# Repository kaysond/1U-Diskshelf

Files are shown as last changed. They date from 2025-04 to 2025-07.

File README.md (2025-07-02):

# 1U-DiskShelf
A 3D-Printable 1U Disk Shelf (4 bays) With Custom SATA Backplane

Board files can be found in the Backplane PCB directory.

Models can be found on [MakerWorld](https://makerworld.com/en/models/1570200-1u-disk-shelf-19-inch-4-bay-10-inch-2-bay) or see the Models directory for CAD files

# License
This project is released under the CC BY-NC-SA 4.0 license. See LICENSE.txt or https://creativecommons.org/licenses/by-nc-sa/4.0/

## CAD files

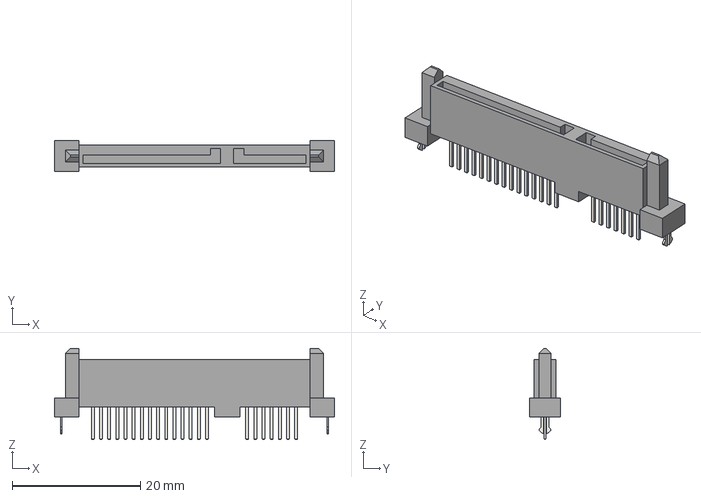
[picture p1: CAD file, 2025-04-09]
Backplane PCB/3D Models/SATA 7+15 Female.step
43.6 x 4.90 x 14.2 mm

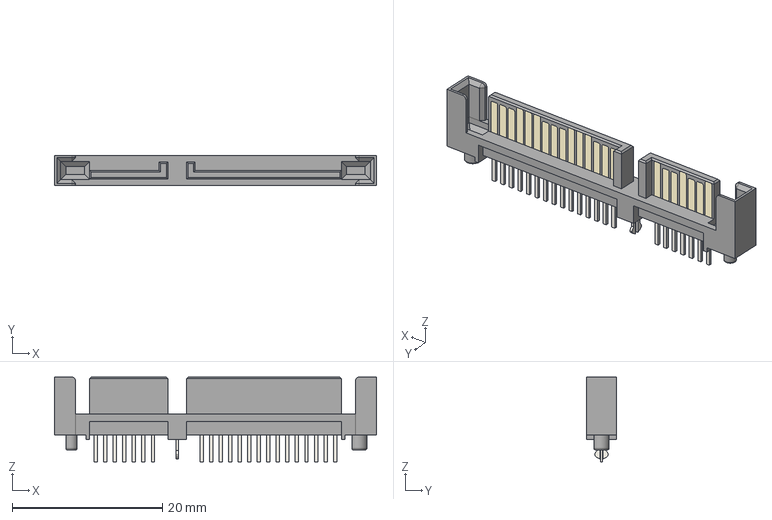
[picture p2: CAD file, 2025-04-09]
Backplane PCB/3D Models/SATA 7+15 Male.step
42.9 x 4.00 x 11.3 mm

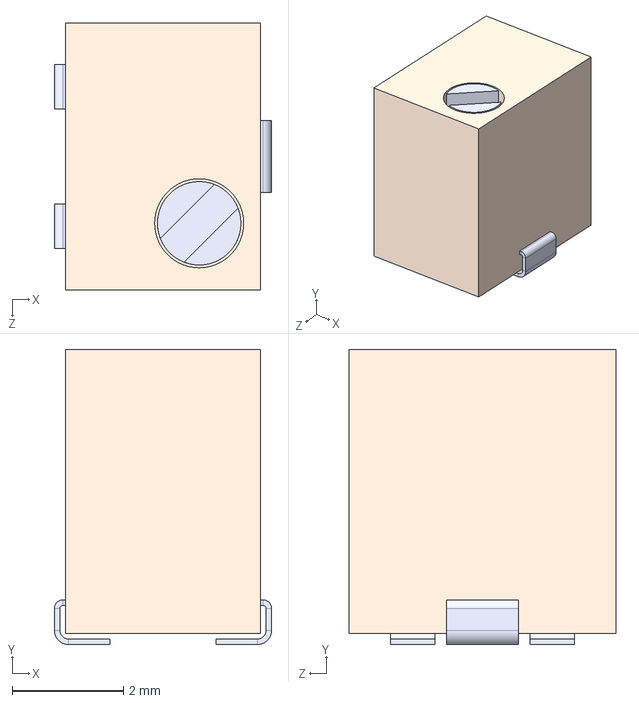
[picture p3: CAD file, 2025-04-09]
Backplane PCB/3D Models/3214W-1-102E.STEP
3.90 x 5.30 x 4.80 mm

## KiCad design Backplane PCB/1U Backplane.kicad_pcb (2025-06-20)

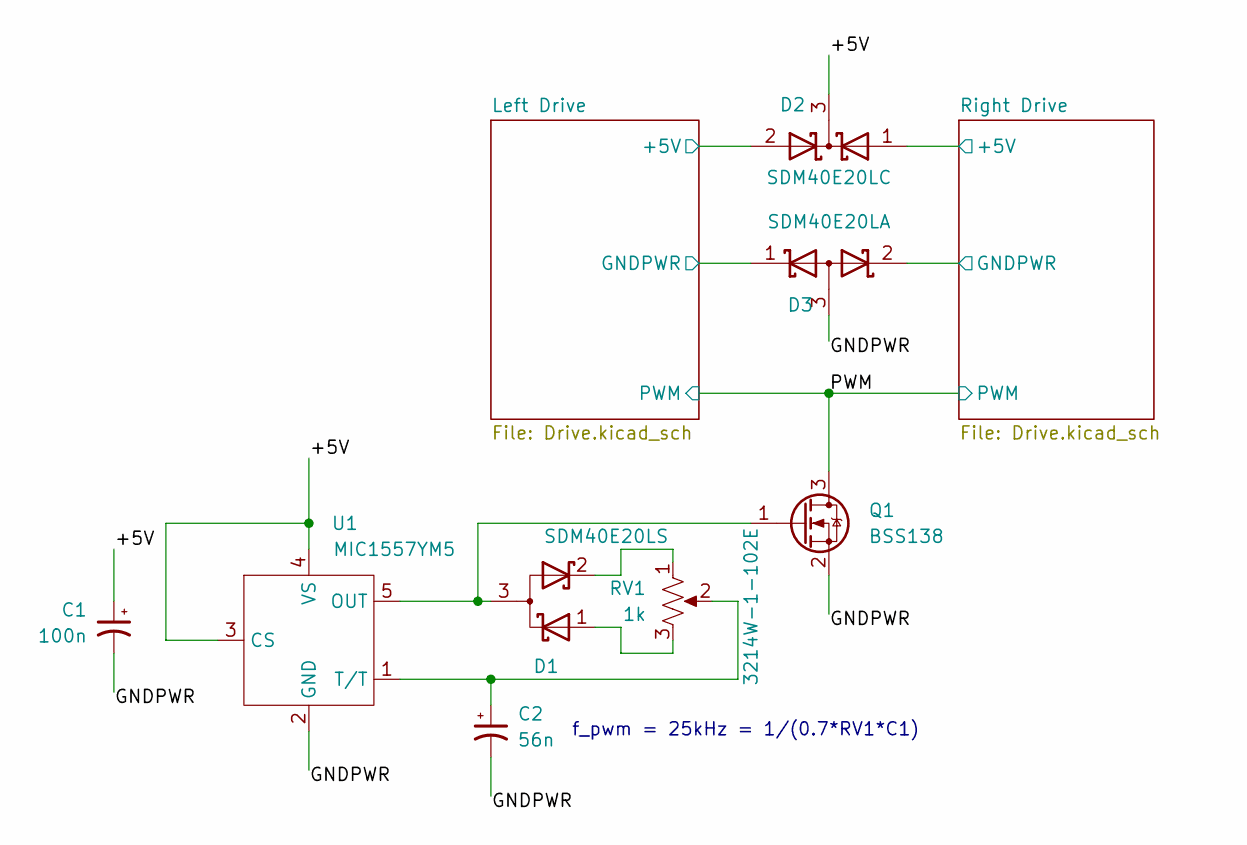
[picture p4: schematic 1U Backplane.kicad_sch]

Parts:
C1: 100n; C_0603_1608Metric_Pad1.08x0.95mm_HandSolder
C2: 56n; C_0603_1608Metric_Pad1.08x0.95mm_HandSolder
D1: SDM40E20LS; SOT-23
D2: SDM40E20LC; SOT-23
D3: SDM40E20LA; SOT-23
Q1: BSS138; SOT-23
RV1: 1k; Potentiometer_Bourns_3214W_Vertical; Part No 3214W-1-102E
U1: MIC1557YM5; SOT-23-5

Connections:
/+5V: C1.1, D2.3 (K), U1.3 (CS), U1.4 (VS)
/GNDPWR: C1.2, C2.2, D3.3 (A), Q1.2 (S), U1.2 (GND)
/Left Drive/+5V: D2.2 (A); also elsewhere on the board
/Left Drive/GNDPWR: D3.1 (K); also elsewhere on the board
/PWM: Q1.3 (D); also elsewhere on the board
/Right Drive/+5V: D2.1 (A); also elsewhere on the board
/Right Drive/GNDPWR: D3.2 (K); also elsewhere on the board
unnamed: D1.3 (A), Q1.1 (G), U1.5 (OUT)
unnamed: D1.1 (K), RV1.3
unnamed: D1.2 (K), RV1.1
unnamed: C2.1, RV1.2, U1.1 (T/T)

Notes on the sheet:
f_pwm = 25kHz = 1/(0.7*RV1*C1)

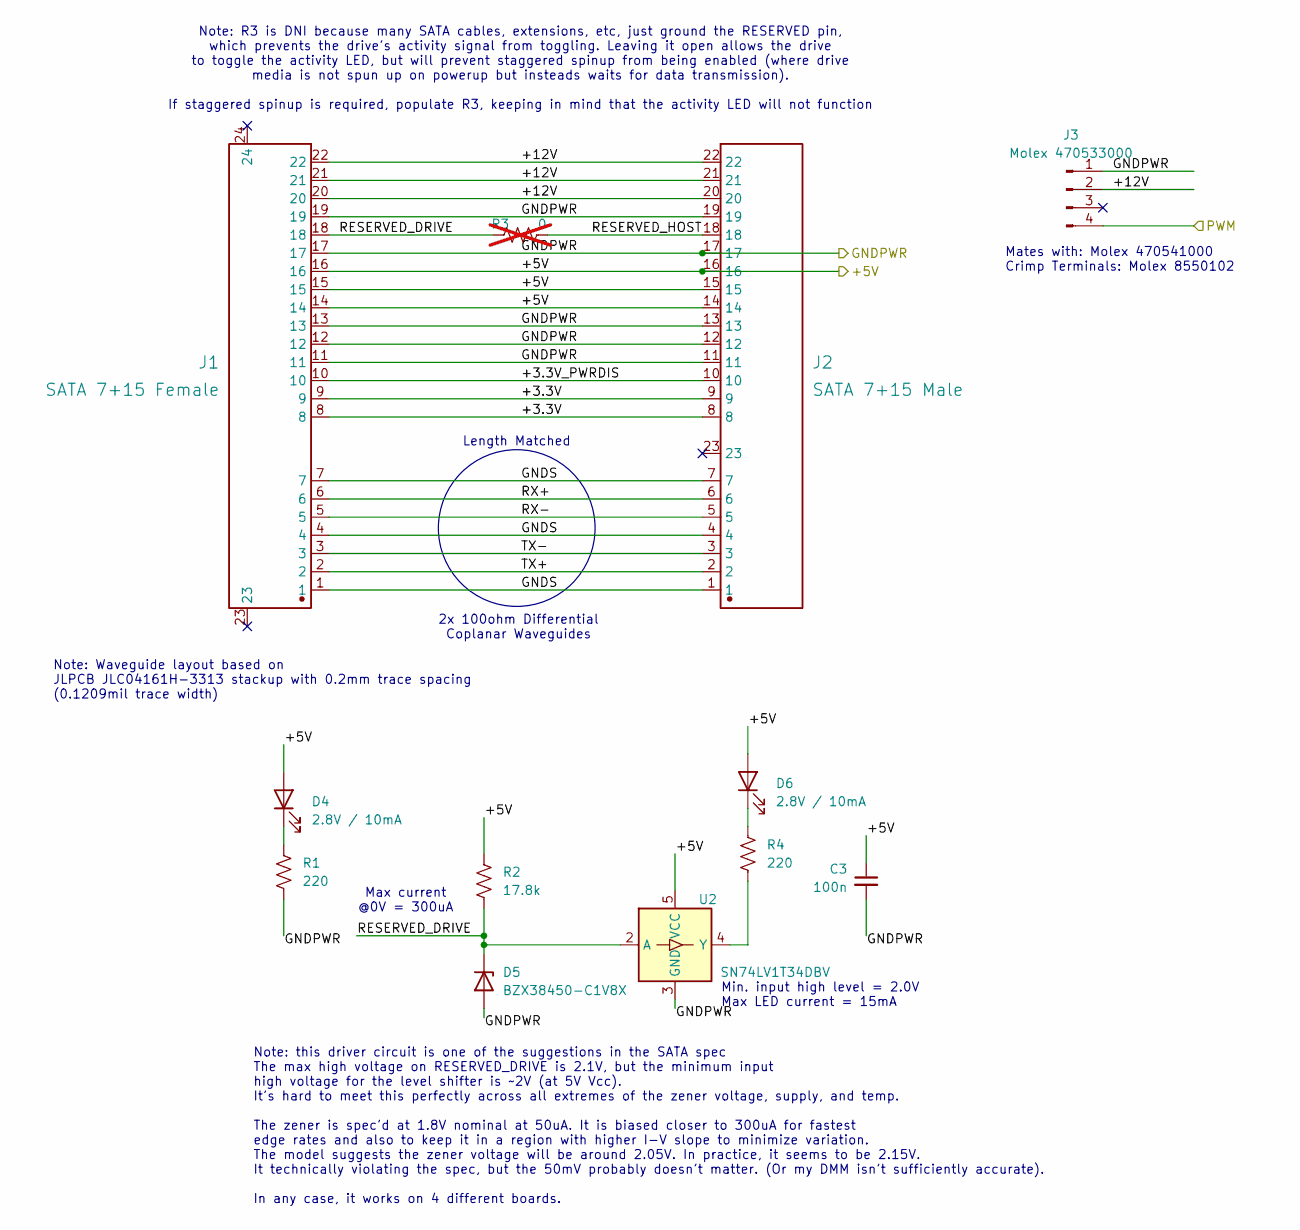
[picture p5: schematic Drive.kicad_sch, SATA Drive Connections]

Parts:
C3: 100n; C_0603_1608Metric_Pad1.08x0.95mm_HandSolder
D4, D6: 2.8V / 10mA; LED_0603_1608Metric_Pad1.05x0.95mm_HandSolder
D5: BZX38450-C1V8X; D_SOD-323_HandSoldering
J1: SATA 7+15 Female; CONN-TH_SATA7-15-TYPE-B; Manufacturer Part SATA 7+15 TYPE-B
J2: SATA 7+15 Male; CONN-TH_SATA7-15-TYPE-A; Manufacturer Part SATA 7+15 TYPE-A
J3: Molex 470533000; Molex_KK-254_AE-6410-04A_1x04_P2.54mm_Vertical
R1, R4: 220; R_0603_1608Metric_Pad0.98x0.95mm_HandSolder
R2: 17.8k; R_0603_1608Metric_Pad0.98x0.95mm_HandSolder
R3: 0; R_0402_1005Metric; not fitted
U2: SN74LV1T34DBV; SOT-23-5

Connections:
/Left Drive/+3.3V: J1.8, J1.9, J2.8, J2.9
/Left Drive/+3.3V_PWRDIS: J1.10, J2.10
/Left Drive/+5V: C3.1, D4.2 (A), D6.2 (A), J1.14, J1.15, J1.16, J2.14, J2.15, J2.16, R2.1, U2.5 (VCC); also elsewhere on the board
/Left Drive/+12V: J1.20, J1.21, J1.22, J2.20, J2.21, J2.22, J3.2
/Left Drive/GNDPWR: C3.2, D5.2 (A), J1.11, J1.12, J1.13, J1.17, J1.19, J2.11, J2.12, J2.13, J2.17, J2.19, J3.1, R1.2, U2.3 (GND); also elsewhere on the board
/Left Drive/GNDS: J1.1, J1.4, J1.7, J2.1, J2.4, J2.7
/Left Drive/RESERVED_DRIVE: D5.1 (K), J1.18, R2.2, R3.1, U2.2 (A)
/Left Drive/RESERVED_HOST: J2.18, R3.2
/Left Drive/RX+: J1.6, J2.6
/Left Drive/RX-: J1.5, J2.5
/Left Drive/TX+: J1.2, J2.2
/Left Drive/TX-: J1.3, J2.3
/PWM: J3.4; also elsewhere on the board
unnamed: D4.1 (K), R1.1
unnamed: D6.1 (K), R4.1
unnamed: R4.2, U2.4 (Y)

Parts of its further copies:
C4: 100n; C_0603_1608Metric_Pad1.08x0.95mm_HandSolder
D7, D9: 2.8V / 10mA; LED_0603_1608Metric_Pad1.05x0.95mm_HandSolder
D8: BZX38450-C1V8X; D_SOD-323_HandSoldering
J4: SATA 7+15 Female; CONN-TH_SATA7-15-TYPE-B; Manufacturer Part SATA 7+15 TYPE-B
J5: SATA 7+15 Male; CONN-TH_SATA7-15-TYPE-A; Manufacturer Part SATA 7+15 TYPE-A
J6: Molex 470533000; Molex_KK-254_AE-6410-04A_1x04_P2.54mm_Vertical
R5, R8: 220; R_0603_1608Metric_Pad0.98x0.95mm_HandSolder
R6: 17.8k; R_0603_1608Metric_Pad0.98x0.95mm_HandSolder
R7: 0; R_0402_1005Metric; not fitted
U3: SN74LV1T34DBV; SOT-23-5

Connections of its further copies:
/PWM: J6.4; also elsewhere on the board
/Right Drive/+3.3V: J4.8, J4.9, J5.8, J5.9
/Right Drive/+3.3V_PWRDIS: J4.10, J5.10
/Right Drive/+5V: C4.1, D7.2 (A), D9.2 (A), J4.14, J4.15, J4.16, J5.14, J5.15, J5.16, R6.1, U3.5 (VCC); also elsewhere on the board
/Right Drive/+12V: J4.20, J4.21, J4.22, J5.20, J5.21, J5.22, J6.2
/Right Drive/GNDPWR: C4.2, D8.2 (A), J4.11, J4.12, J4.13, J4.17, J4.19, J5.11, J5.12, J5.13, J5.17, J5.19, J6.1, R5.2, U3.3 (GND); also elsewhere on the board
/Right Drive/GNDS: J4.1, J4.4, J4.7, J5.1, J5.4, J5.7
/Right Drive/RESERVED_DRIVE: D8.1 (K), J4.18, R6.2, R7.1, U3.2 (A)
/Right Drive/RESERVED_HOST: J5.18, R7.2
/Right Drive/RX+: J4.6, J5.6
/Right Drive/RX-: J4.5, J5.5
/Right Drive/TX+: J4.2, J5.2
/Right Drive/TX-: J4.3, J5.3
unnamed: D7.1 (K), R5.1
unnamed: D9.1 (K), R8.1
unnamed: R8.2, U3.4 (Y)

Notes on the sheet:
Note: Waveguide layout based on JLPCB JLC04161H-3313 stackup with 0.2mm trace spacing (0.1209mil trace width)
Min. input high level = 2.0V
Note: R3 is DNI because many SATA cables, extensions, etc, just ground the RESERVED pin, which prevents the drive's activity signal from toggling. Leaving it open allows the drive to toggle the activity LED, but will prevent staggered spinup from being enabled (where drive media is not spun up on p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
Length Matched
Max current @0V = 300uA
Max LED current = 15mA
Mates with: Molex 470541000 Crimp Terminals: Molex 8550102
2x 100ohm Differential Coplanar Waveguides
Note: this driver circuit is one of the suggestions in the SATA spec The max high voltage on RESERVED_DRIVE is 2.1V, but the minimum input high voltage for the level shifter is ~2V (at 5V Vcc). It's hard to meet this perfectly across all extremes of the zener voltage, supply, and temp. The zener is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

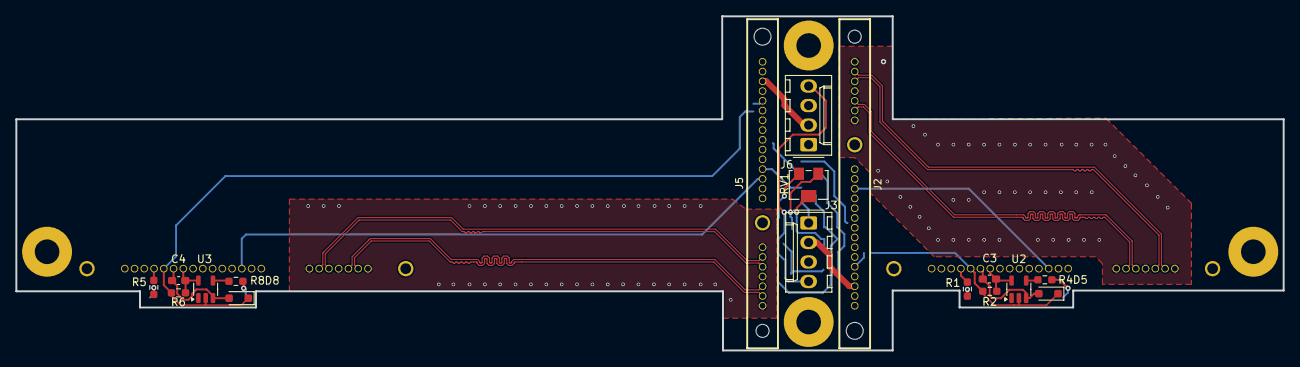
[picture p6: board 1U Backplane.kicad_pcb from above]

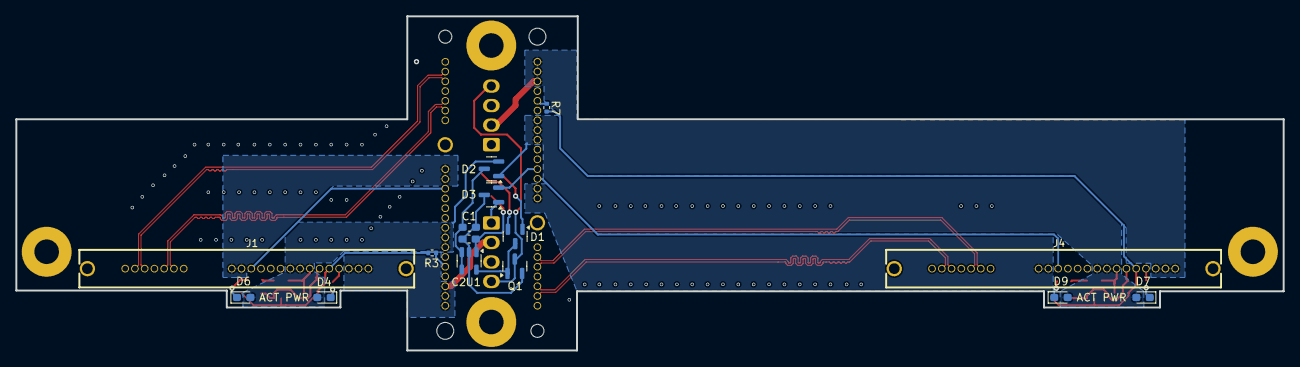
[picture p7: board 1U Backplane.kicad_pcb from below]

Board: 4 copper layers, 165.0 x 43.5 mm, 36 parts (15 on the bottom side), 37 nets.

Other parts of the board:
Pad_gge6706, Pad_gge8659, Pad_gge8677, Pad_gge8716: M3 Screw Mount Hole

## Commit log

2025-04-09 Initial commit of PCB design
    [1U Backplane.kicad_pcb, 1U Backplane.kicad_sch, 3214W-1-102E.STEP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]
2025-06-20 Update PCB
    [1U Backplane-B_Adhesive.gbr, 1U Backplane-BoardOutLine.gbr, 1U Backplane-BottomLayer.gbr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]
2025-07-02 Add CAD models
